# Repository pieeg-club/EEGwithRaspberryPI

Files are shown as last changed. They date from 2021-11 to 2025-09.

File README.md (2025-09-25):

Actual locations for the scripts will be [here](https://github.com/pieeg-club/PiEEG) , now just only Python.

### To Buy - PiEEG is available in the market at our partner shop [Elecrow](https://pieeg.com/pieeg/)

This project is the result of several years of work on the development of BCI. We believe that the easiest way to get started with biosignals is to use a shield.
We will try to reveal the process of reading EEG signals as fully and clearly as possible. 

### GUI
PiEEG it is a low-cost brain-computer interface that allows measuring EEG via RaspberryPI  
[Manual](https://colab.research.google.com/drive/1xW6fwzVdLH83zHoorjeWai6SdZoOanfA#scrollTo=9bxgisvWfs5f)    
[Manual for quick start ](https://github.com/pieeg-club/PiEEG/blob/main/Manual.%20Conenction%20and%20start%20-%20PiEEG1.pdf)    
PiEEG SDK [video maual](https://youtu.be/9jLyN2zRXdU)     
Practical Python Signal Processing [course in Udemy](https://www.udemy.com/course/signal-processing-python-for-eeg/?referralCode=2D537B5EAD7114C43DE2) comfortable for PiEEG 

https://pieeg.com/  
Contact: pieeg@pieeg.com  

aloha

aloha

## Signal test
#### Alpha in EEG signal
aloha

#### Artefacts (chewing and blinking) in EEG signal

artefacts

#### EMG signal
emg

#### EKG signal 
artefacts

#### Pinout between Pi and PiEEG  
 
spi

Connect the shield to Raspberry Pi which is supplied via a 5V battery (power supply) and connect electrodes.
Full galvanic isolation from mains is required.  
This also applies to the monitor. Use only a monitor that is powered by the Raspberry Pi, as in the picture below, left. Electrodes are positioned according to the International 10-20 system, right    
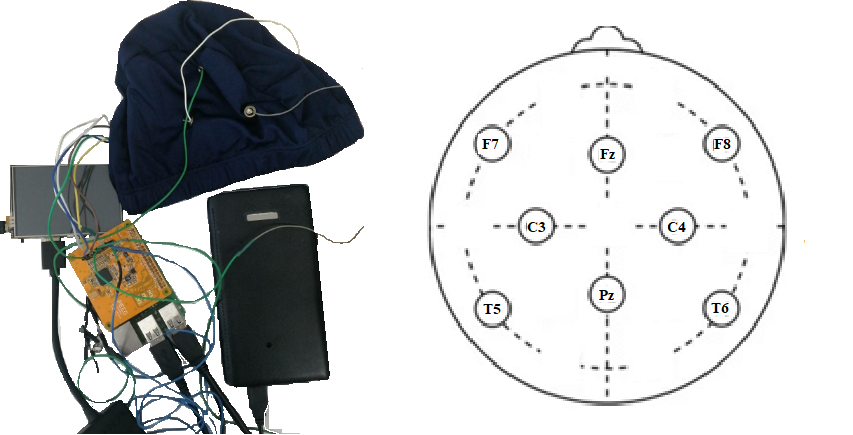
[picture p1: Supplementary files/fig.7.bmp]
general view


#### How to start  
How to start (https://youtu.be/zOxcixEGeE8)  

#### Warnings
>[!WARNING]
> PiEEG  is not medical device. You are fully responsible for your personal decision to purchase this device and, ultimately, for its safe use. PiEEG is not a medical device and has not been certified by any government regulatory agency for use with the human body. Use it at your own risk.  

>[!CAUTION]
> The device must operate only from a battery - 5 V. Complete isolation from the mains power is required.! The device MUST not be connected to any kind of mains power, via USB or otherwise.   
> Power supply - only battery 5V, please read the [liability](https://pieeg.com/liability/)

#### Citation    
I. Rakhmatuiln, et all. (2021). Raspberry Pi Shield - for measure EEG (PIEEG). 2021 5th International Conference on Electrical, Electronics, Communication, Computer Technologies and Optimization Techniques (ICEECCOT), 410-413. DOI: 10.1109/ICEECCOT52851.2021.9707969  [link](https://ieeexplore.ieee.org/document/9707969)

#### Contacts  
http://pieeg.com/  
pieeg@pieeg.com

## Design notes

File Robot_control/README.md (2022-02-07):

# Control the robot by blinking

For example, discrete output channels from GPIO can be connected directly or through a relay to the control panel of radio-controlled toy robots.  
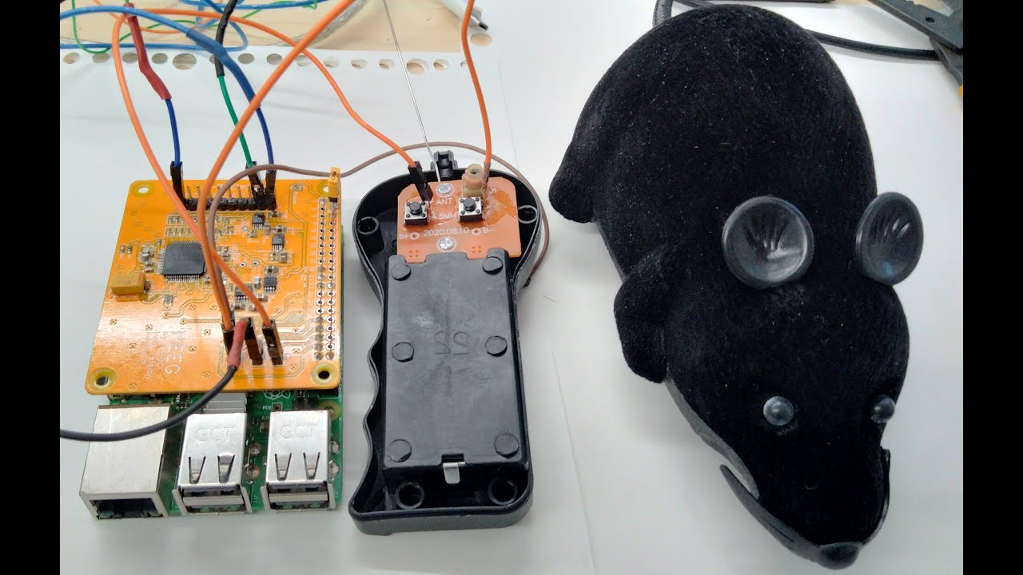
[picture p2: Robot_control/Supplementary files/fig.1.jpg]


Run - robot_control.py   

Connect motor to GPIO in the next points  
GPIO.setup(31, GPIO.OUT)  
GPIO.setup(35, GPIO.OUT)  

set frequency range here - "fourier Transform[0:3]"  
set amplitude here - "blinking_value"   
the best value must be found experimentally    

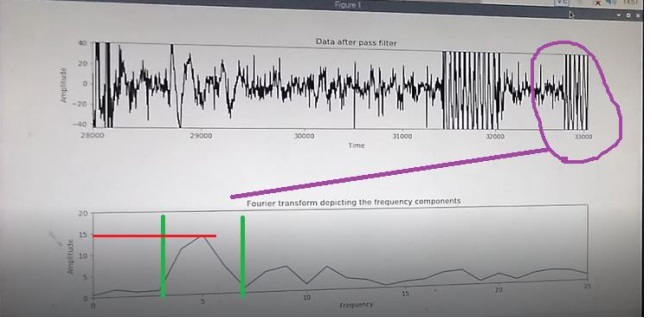
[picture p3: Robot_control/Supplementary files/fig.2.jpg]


(upper graph) - EEG signal through pass filter 1-30 Hz. Lower graph - EEG signal received through the Fast Fourier Transform (the part circled in purple from the graph above). The red line is the setting for turning on the LED, green lines are the frequency range in which we monitor the signal amplitude. (lower graph) – LED circled in blue, output - 31 for GPIO.setmode (GPIO.BOARD)    

We can see in the lower graph for  various frequency ranges, dependence amplitudes from the frequency of  blinking (5 Hz and 3 Hz)
We can set the threshold to the amplitude and connected two diodes. If the amplitude (lower graph) at a frequency of 1-3 Hz becomes more than the threshold, then the upper LED will light up.
If the amplitude (lower graph)  at a frequency of 3-5 Hz becomes more than the threshold, then the lower LED will light up.

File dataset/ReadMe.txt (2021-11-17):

Raw data
1. 1.Shorted_ Raw_Data.txt - Noise measure. The first channel shorted with reference via cable, other channels - internally by register - 0x01.    
2. Artifacts measure. 
3. Alpha rhythm. Soon will be uploaded.

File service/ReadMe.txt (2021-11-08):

VREF = VREFP – VREFN (Note: internal reference buffer must be enabled)
//VCAP1 = AVSS + 1.2 V
VCAP2 = (AVDD + AVSS) / 2
VCAP3 = AVDD + 1.9 V
VCAP4 = (VREFP + VREFN) / 2
VREFP_VREFN  = 4.5 V

VCAP1 = -1.2V

VCAP2 = 0.001V

VCAP3 = 4.2V

VCAP4=-0.125V

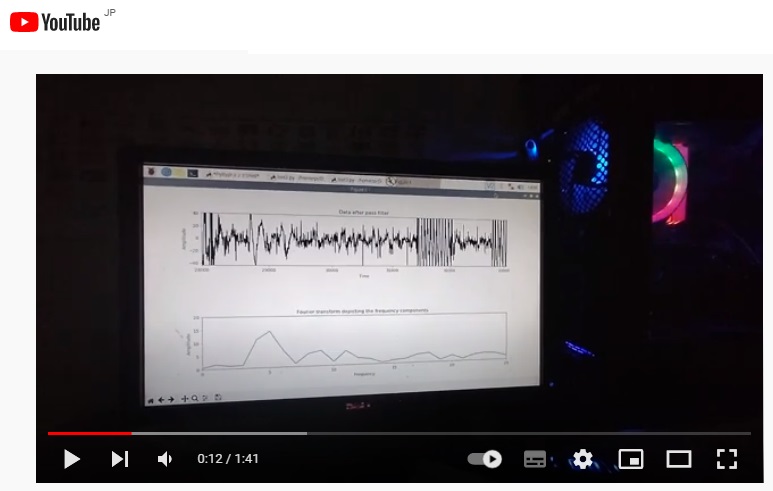
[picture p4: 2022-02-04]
Supplementary files/fig.18.jpg

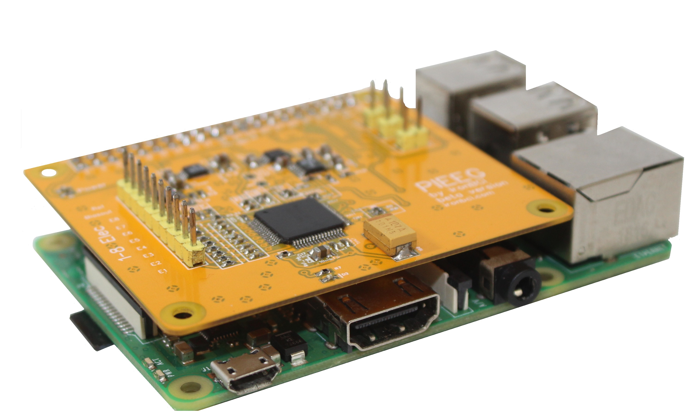
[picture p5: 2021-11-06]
Supplementary files/Fig.3.jpg

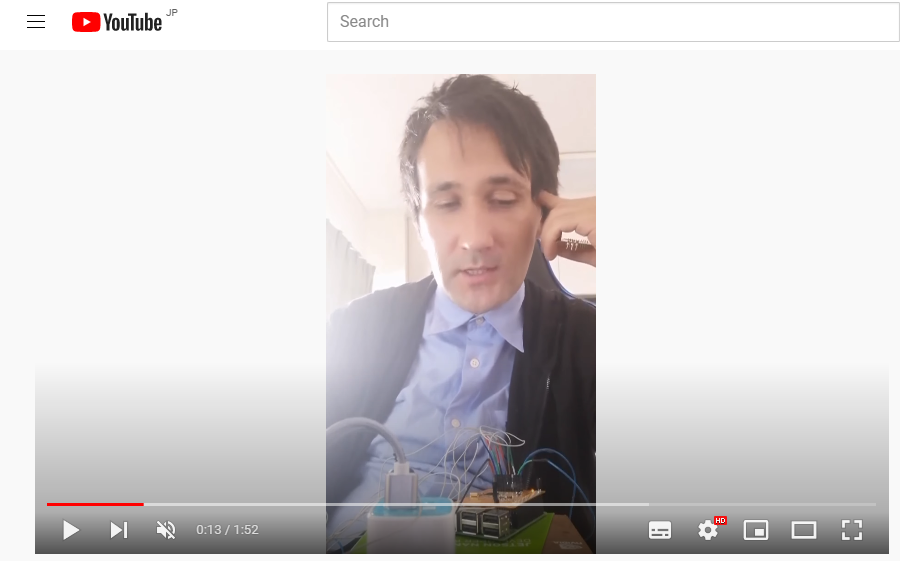
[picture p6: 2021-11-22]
Supplementary files/fig.13.bmp

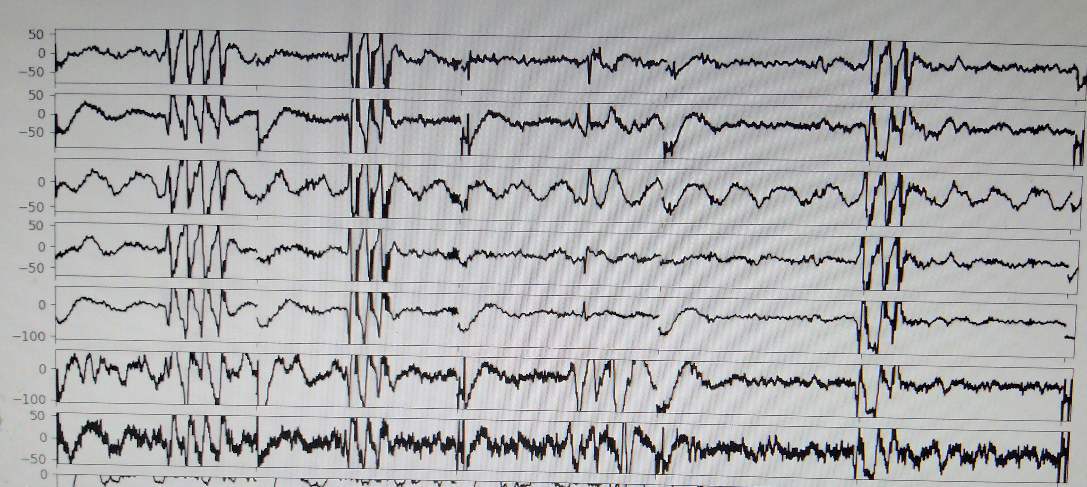
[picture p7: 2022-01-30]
Supplementary files/fig.16.jpg

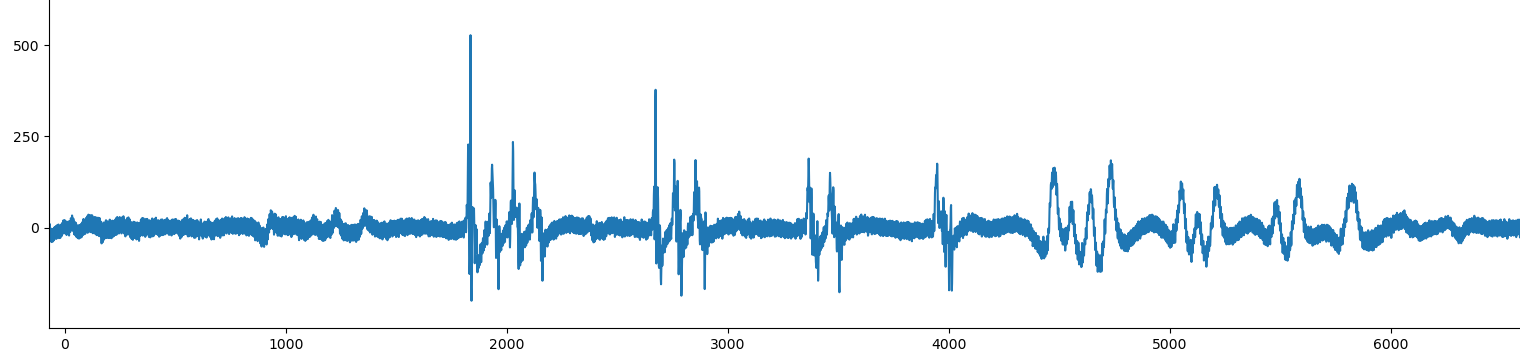
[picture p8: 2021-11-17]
Supplementary files/fig.10.band_bass.bmp

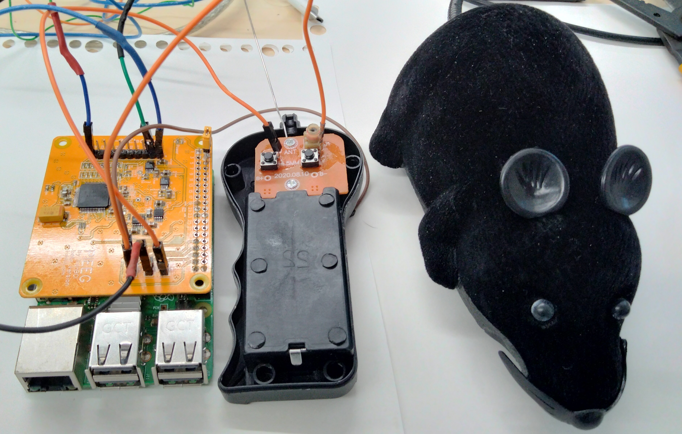
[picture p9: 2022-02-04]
Supplementary files/fig.17.jpg

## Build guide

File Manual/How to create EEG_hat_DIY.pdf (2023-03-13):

DIY - Hat for measuring EEG with dry electrodes for PiEEG

Ildar Rakhmatulin, PhD, PiEEG
ildarr2016@gmail.com

Source https://github.com/Ildaron/EEGwithRaspberryPI

Keywords: PiEEG, EEG, BCI, machine learning, RaspberryPi

Introduction
This document provides step-by-step instructions on how to create a custom Hat for measuring electroencephalography (EEG) signals using dry electrodes, specifically designed for use with PiEEG [1,2,3]. Creating your own Hat for measuring EEG signals with dry electrodes is an affordable and customizable solution for capturing EEG data. This datasheet provides detailed instructions and a list of materials needed to create your Hat, as well as information on how to assemble and use it with your PiEEG. With this DIY approach, you can save costs and have more control over the design of your EEG measurement system. We used available materials without any special skills or tools.

Materials
The electrodes used in this work are Ag-AgCl - Silver chloride electrodes with a hole in the center for installation, Fig.1.

Fig.1. Examples of valid Silver chloride electrodes

To attach the electrode to the hat, a bolt can be used, the diameter of which should be smaller than the hole in the center of the electrode. It is necessary to use bolts with length 3-5 centimeter, washer, nut - M1, Fig.2.

Fig.2. Parts for attaching the electrode to the hat

It is recommended to use Copper cables (stranded, 1-3 mm) as wires, the length is set depending on the needs, Fig.3.

Fig.3. Wires for attaching to the electrode

Strap can be used as hat, for example strap for Camera Mount hat. Electrodes can be located in line international "10-20" electrode placement system, Fig.4.

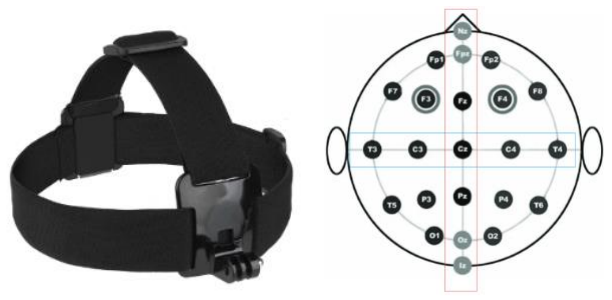
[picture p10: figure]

a | b

Fig.4. a - Camera Mount hat, b – arrange the electrodes according to the international "10-20" electrode placement system

Instructions
Prepare cables. Strip the wires of isolation, a few centimeters, as showed in the Fig. 5.

Fig.5. Cable preparation

To connect the electrode to the cap, it is necessary to take the bolt, nuts, washers, cable - 1 and the EEG cap - 2. First clamp the cable between the nut and the bolt, then thread the bolt through the cap and fix it on the other side with the nut, as shown in Fig.6.

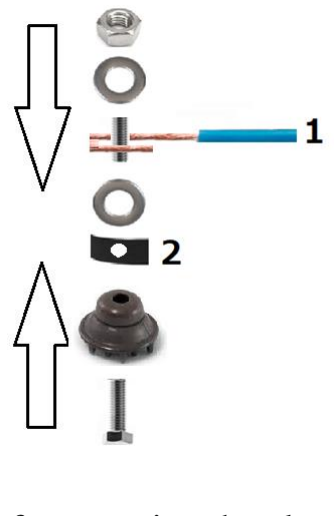
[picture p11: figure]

Fig.6. Scheme of connecting the electrode with a hat

As a result, the prepared electrode should look like shown in Fig.7.

Fig.7. Electrodes prepared for installation in the hat

Next, it is necessary, in accordance with according to the international "10-20" electrode placement system, make holes for electrodes in the hat, insert the electrode and fix it with a bolt from the other side of the hat, Fig. 8.

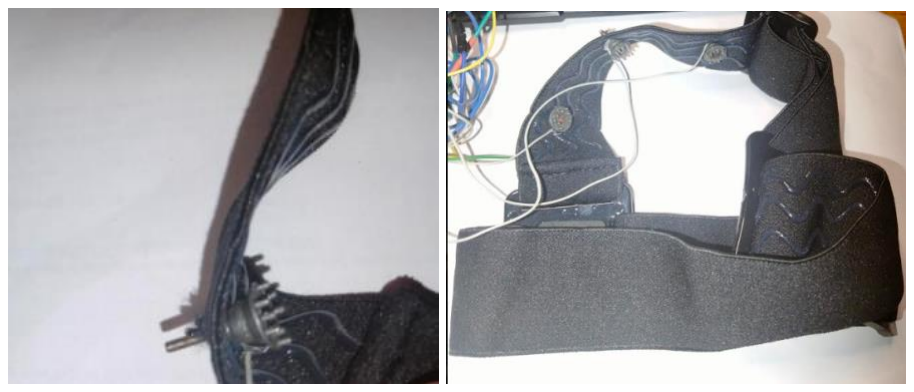
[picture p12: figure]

Fig.8. An example of installing electrodes in a hat

The pressure of the electrode on the head is adjusted independently as far as is comfortable, the clamping force depends largely on the cap material used, and each electrode must be adjusted manually after the cap has been fitted.
The connection of the electrodes to the PEEEG board is shown in Figure 9. Even to measure one EEG channel, 4 electrodes are required, 1 - the EEG electrodes themselves, 2 - the reference electrode, 3 - the ground electrode and 4 - the bias electrode to eliminate common mode interference.

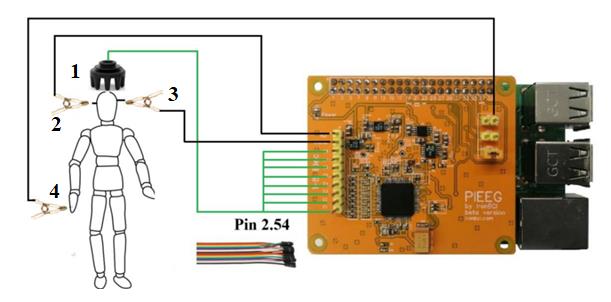
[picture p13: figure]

Fig.9. Scheme of connecting electrodes to the PEEG plan: 1 – EEG electrode, 2 – reference electrode, 3 – ground electrode, 4 – bias electrode

Conclusion
This paper presents one of the simplest ways to make a cheap alternative to a hat for adjusting EEG signals. The main advantage is the low cost. This cap is largely designed to work in conjunction with the PIEEG board and is only intended to be a first step into the world of neuroscience. This is only an example, the ideas proposed in this work can be improved, supplemented, and modified.

Additional Information
- Overview of dry electrodes [4]
- Additional Information Machine learning to identify alcoholism [5]
- Signal processing [6]
- Machine learning for [7]

Conflicts of interest: none Funding: none

Ethical approval: not required

References
1. Rakhmatuiln, I., Zhanikeev, M., and Parfenov, A. (2021). Raspberry PI Shield - for measure EEG (PIEEG)," 2021 5th International Conference on Electrical, Electronics, Communication, Computer Technologies and Optimization Techniques (ICEECCOT), Mysuru, India, 2021, pp. 410-413, doi: 10.1109/ICEECCOT52851.2021.9707969
2. Rakhmatulin, I., Sebastian Volkl, S. (2021). PIEEG: Turn a Raspberry Pi into a Brain-Computer-Interface to measure biosignals. arXiv:2201.02228, https://doi.org/10.48550/arXiv.2201.02228
3. Rakhmatulin, I., Sebastian Volkl, S. (2021). Brain-Computer-Interface controlled robot via RaspberryPi and PiEEG. arXiv:2202.01936. https://doi.org/10.48550/arXiv.2202.01936
4. Rakhmatulin, I.; Gan, Y. Review Dry and Non-Contact EEG Electrodes for 2010-2021 Years. Preprints 2021, 2021030555. https://doi.org/10.20944/preprints202103.0555.v1
5. Rakhmatulin, I. (2021). Deep learning and machine learning for EEG signal processing on the example of recognizing the disease of alcoholism. Medrxiv. doi: https://doi.org/10.1101/2021.06.02.21258251
6. Rakhmatulin, Ildar, Review of EEG Feature Selection by Neural Networks (August 17, 2020). International Journal of Science and Business, Volume 4, issue 9, 101-112, 2020 DOI: 10.5281/zenodo.3987894, ISSN 2520-4750 (Online) & ISSN 2521-3040 (Print), Available at SSRN: https://ssrn.com/abstract=3675950 or http://dx.doi.org/10.2139/ssrn.3675950
7. Rakhmatulin, I. (2021). Progress in neural networks for EEG signal recognition in 2021. arXiv:2103.15755. https://doi.org/10.48550/arXiv.2103.15755

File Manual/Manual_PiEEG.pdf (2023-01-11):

RaspberryPi to measure EEG, ECG, EMG and EOG with Shield PiEEG

In this paper presented hardware and software for shield PiEEG for reading signals through the families of single-board computers - RaspberryPi, OrangePi, BananaPi, etc. For the most part, the paper provides technical information on how to implement this device. This device is designed to be familiar with neuroscience and is one of the easiest ways to get started with EEG measurements.

Ildar Rakhmatulin, PhD, PiEEG, ildarr2016@gmail.com
Source https://github.com/Ildaron/EEGwithRaspberryPI
Presentation https://youtu.be/uK8QF2liO5U

Keywords: RaspberryPi and EEG, ECG, EMG and EOG; brain-computer interface; shield for RaspberryPi

### 1. Introduction

The brain-computer interface is a device for reading brain signals in order to identify any correlations that can be used for practical purposes. In 2021 we developed the brain-computer interface - ironbci [1,2,3] but the chip shortage significantly increased the cost of the device, after which we switched to PiEEG shield, which made it possible to reduce the cost of the device and simplify the installation process. The PiEEG device was presented in general terms at the conference [4] and in the publication [10]. In this paper we will focus more on the technical details of the implementation of this device.

### 2. Safety recommendation

The developed device was tested only for Raspberry Pi. During the test, it is forbidden connect the device to the electrical source, this need for safety and to avoid network interference. Cannot be used this device when powered via an electrical network and used it only when working with 5V batteries (capacity– not mote 2000 mAh). General view of the complete assembly of the device in Fig.1.

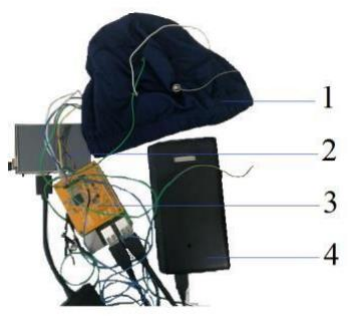
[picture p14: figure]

Fig.1 General View of assembled device: 1 – hat EEG, 2 – monitor, 3 – RaspberryPI and shield EEG, 4 – power bank

All parts should be connected only with battery – monitor, keyboard, mouse, RaspberryPI and PiEEG device. The device is connected only directly through GPIO40 to the Raspberry Pi. There must not be any connections for any elements with the electrical network.
Also observe the following protective measures:
- If the device fails (heating of components, smoke etc. ), switch off immediately;
- When you have finished using any electrical appliance, be sure to turn it off and unplug it;
- Never try to fix a malfunction in an electrical appliance yourself;
- Do not touch the components on the board when the device is turned on.

### 3. Connecting the device

The device is designed to allow single-board computers to read the EEG signal via the SPI protocol from ADS1299. The next single computers can be connected (not tested yet) - OrangePi, BananaPi, and the device can be connected via wires to the input of the microcontroller if necessary, Fig.2.

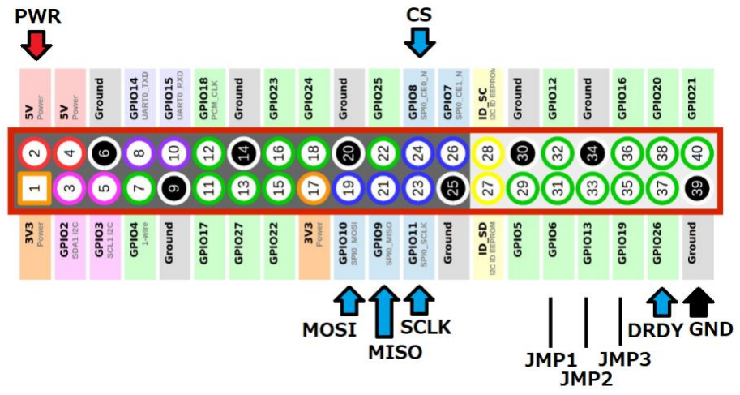
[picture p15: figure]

Fig.2. Device connection scheme, GPIO40

### 4. Software

Data transfer between Raspberry Pi and ADS1299 using the SPI protocol is written in C at a rate of 250 samples per second for each channel. Data processing realized in Python 3. Software files details from https://github.com/Ildaron/EEGwithRaspberryPI/tree/master/GUI :
libperiphery.a (https://github.com/Ildaron/EEGwithRaspberryPI/blob/master/GUI/libperiphery.a) – static library compiled from https://github.com/vsergeev/c-periphery ,
real_time.py (https://github.com/Ildaron/EEGwithRaspberryPI/blob/master/GUI/real_time.py) – script for editing processing signal and data visualization,
real_time_massive.c (https://github.com/Ildaron/EEGwithRaspberryPI/blob/master/GUI/real_time_massive.c) – header call,
real_time_massive.h (https://github.com/Ildaron/EEGwithRaspberryPI/blob/master/GUI/real_time_massive.h) – register setting for data transfer protocol,
super_real_time_massive.so (https://github.com/Ildaron/EEGwithRaspberryPI/blob/master/GUI/super_real_time_massive.so) – compiled dynamic library.

To start the reading EEG signals is possible to write software or download from the git https://github.com/Ildaron/EEGwithRaspberryPI , then go to the folder - GUI and run the file -real_time.py. An example of reading is shown in the figure in Fig.3.

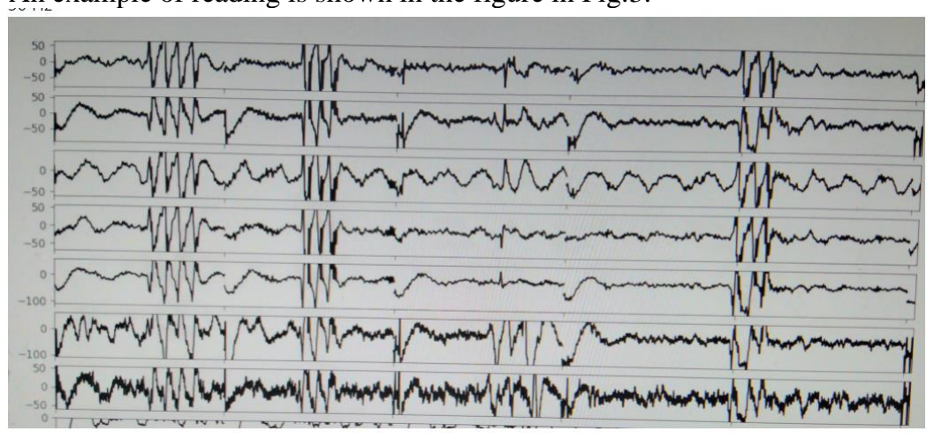
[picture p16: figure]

Fig.3. EEG signals after band pass filter 1-30 Hz

Through the python script, is possible to configure the parameters for band pass filters. Signal processing is implemented using the standard scipy library. Through the C file, once per second we receive a data packet of 2000 data, 250 samples per second for each channel.
Currently we used the next setting for registers for ADS1299:
write_reg (0x14,0x80);//led write_reg (0x05,0x00);//ch1 write_reg (0x06,0x01);//ch2 write_reg (0x07,0x01);//ch3 write_reg (0x08,0x01);//ch4 write_reg (0x0D,0xFF);//bias N write_reg (0x0E,0x00);//bias P write_reg (0x09,0x01);//ch5 write_reg (0x0A,0x01);//ch6 write_reg (0x0B,0x01);//ch7 write_reg (0x0C,0x01);//ch8 write_reg (0x15,0x20);// mics write_reg (0x01,0x96);// reg1 write_reg (0x02,0xD4);// reg2 write_reg (0x03,0xE0);// reg3 send_command (0x10);//sdatc send_command (0x08);//start

To change the ADS1299 registers, needs to work with the header file - real_time_massive.h, after any changes, need to recompile the static library, following the next steps for GPIO library for Linux from https://github.com/vsergeev/c-periphery:
$ mkdir build
$ cd build
$ cmake ..
$ make
That allows receiving the Static Library - libperiphery.a and finally to create a dynamic library for .so -
gcc | -shared | -home/pi/Desktop/new_spi/c-periphery-master/src | real_time_massive.c
/home/pi/Desktop/new_spi/c-periphery-master/build/libperiphery.a -o super_real_time_massive.so This library can be imported in python script with signal processing (example - real_time.py) via standard library – ctypes.
In case of errors incompatibility in a python IDE, it is necessary to check the versions of installed libraries https://github.com/Ildaron/EEGwithRaspberryPI/blob/master/pip.txt
The PIEEG device has a diode connected to the ADS1299, which lights up when the PiEEG device is initialized. If the life bit is not burning, it is necessary to check the power (Fig.4) in the next points:
| TP1: – 2.5V TP2: 3.3V TP3: 2.5V

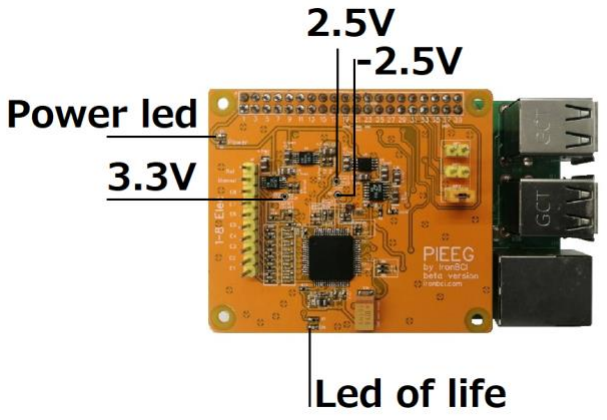
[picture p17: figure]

Fig.4. Test points in the PiEEG board

If there is noise in the measured EEG signals that goes beyond the limits declared in the device it is necessary to check the voltage in the next points:
VCAP1 = -1.2V
VCAP2 = 0.001V
VCAP3 = 4.2V
VCAP4=-0.125V

### 5. Conclusion and perspectives

This device is positioned as an easy way to start measuring EEG signals. We introduced hardware and software for reading and processing data in real-time in open source format. We demonstrated how to control a robot using a device [5], in the future we will work on the P300 and on other paradigms, then we plan to gather a team of like-minded people and collect the necessary amount of data to control robots through the motor imagery method. Fig.5 shows a block diagram for the possibility areas of use of the device.

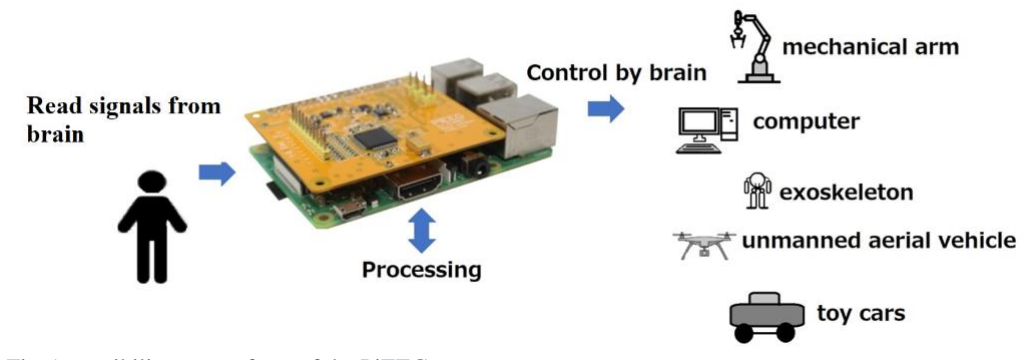
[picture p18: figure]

Fig.5. possibility areas of use of the PiEEG

Additional Information
Machine learning to identify alcoholism [9], Overview of dry electrodes [6],
Signal processing [7,8] .

References
1. Rakhmatulin, I., Parfenov, A., Traylor, Z. et al. (2021). Low-cost brain computer interface for everyday use. ExpBrain Res 239, 3573–3583. https://doi.org/10.1007/s00221-021-06231-49
2. Rakhmatulin, I. (2021). ironbci - Open-source Brain-computer interface with the embedded board to monitor the physiological subject's condition and environmental parameters arXiv:2111.03656
3. Rakhmatulin, I . (2021). The electronic board to replace the reference voltage on the earlobe for EEG measurement. March 2021Measurement 173 DOI: 10.1016/j.measurement.2020.108673
4. Rakhmatulin, I. et al. (2021). Raspberry PI Shield - for measure EEG (PIEEG). Conference: 2021 5th International Conference on Electrical, Electronics, Communication, Computer Technologies and
Optimization | Techniques | (ICEECCOT). | DOI: | 10.1109/ICEECCOT52851.2021.9707969
5. I Rakhmatulin, S Volkl. (2022). Brain-Computer-Interface controlled robot via RaspberryPi and PiEEG, arXiv preprint arXiv:2202.01936
6. Rakhmatulin, I., Gan, Y. Review Dry and Non-Contact EEG Electrodes for 2010-2021 Years. Preprints 2021, 2021030555. doi:10.20944/preprints202103.0555.v1
7. Rakhmatulin, I. (2020). Review of EEG Feature Selection by Neural Networks. Int. J. Sci. Bus. 2020, 4, 101–112. http://dx.doi.org/10.2139/ssrn.3675950
8. Ildar, R. (2021). Progress in neural networks for EEG signal recognition in 2021. arXiv preprint arXiv:2103.15755
9. Rakhmatulin, I. (2020). Deep learning and machine learning for EEG signal processing on the example of recognizing the disease of alcoholism. https://doi.org/10.1101/2021.06.02.21258251
10. I Rakhmatulin, S Volkl. (2022). PIEEG: Turn a Raspberry Pi into a Brain-Computer-Interface to measure biosignals. arXiv:2201.02228

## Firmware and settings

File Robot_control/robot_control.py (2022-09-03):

import ctypes
import time
import numpy as np
from numpy.ctypeslib import ndpointer
import sys
import pandas as pd
from scipy import signal
import matplotlib.pyplot as plt
import threading
from RPi import GPIO
import scipy.fftpack

GPIO.setmode(GPIO.BOARD)
GPIO.cleanup()
GPIO.setwarnings(False)
GPIO.setup(31, GPIO.OUT)
GPIO.setup(35, GPIO.OUT)

np.set_printoptions(threshold=sys.maxsize)
libc = ctypes.CDLL("./super_real_time_massive_sec.so")
libc.prepare()

def receive_data():
    libc.real.restype = ndpointer(dtype = ctypes.c_int, shape=(sample_len,8))    
    datas=libc.real()
    data=datas.copy()
    return data

def butter_bandpass(lowcut, highcut, fs, order=5):
    nyq = 0.5 * fs
    low = lowcut / nyq
    high = highcut / nyq
    b, a = signal.butter(order, [low, high], btype='band')
    return b, a
 	 
def butter_bandpass_filter(data, lowcut, highcut, fs, order=5):
    b, a = butter_bandpass(lowcut, highcut, fs, order=order)
    data = signal.lfilter(b, a, data)
    return data

def graph (ch,a):
 data = (data_array[:,[ch]])
 data = list(data.flatten())
 
 sine ['data'+str(a)] = data
 if a==0:
  z = sine ['data1']           
  z = np.append(z, (sine ['data2']))
  z = np.append(z, (sine ['data3']))
  z = np.append(z, (sine ['data4']))
  z = np.append(z, (sine ['data5']))
  z = np.append(z, (sine ['data6']))
  z = np.append(z, (sine ['data7']))
  z = np.append(z, (sine ['data0']))
 if a==1:
  z = sine ['data2']          
  z = np.append(z, (sine ['data3']))
  z = np.append(z, (sine ['data4']))
  z = np.append(z, (sine ['data5']))
  z = np.append(z, (sine ['data6']))
  z = np.append(z, (sine ['data7']))
  z = np.append(z, (sine ['data0']))
  z = np.append(z, (sine ['data1']))                      
 if a==2:
  z = sine ['data3']         
  z = np.append(z, (sine ['data4']))
  z = np.append(z, (sine ['data5']))
  z = np.append(z, (sine ['data6']))
  z = np.append(z, (sine ['data7']))
  z = np.append(z, (sine ['data0']))
  z = np.append(z, (sine ['data1']))
  z = np.append(z, (sine ['data2']))                        
 if a==3:
  z = sine ['data4']   
  z = np.append(z, (sine ['data5']))
  z = np.append(z, (sine ['data6']))
  z = np.append(z, (sine ['data7']))
  z = np.append(z, (sine ['data0']))
  z = np.append(z, (sine ['data1']))
  z = np.append(z, (sine ['data2']))
  z = np.append(z, (sine ['data3']))            
 if a==4:      
  z = sine ['data5']   
  z = np.append(z, (sine ['data6']))
  z = np.append(z, (sine ['data7']))
  z = np.append(z, (sine ['data0']))
  z = np.append(z, (sine ['data1']))
  z = np.append(z, (sine ['data2']))
  z = np.append(z, (sine ['data3']))
  z = np.append(z, (sine ['data4']))            
 if a==5:       
  z = sine ['data6']   
  z = np.append(z, (sine ['data7']))
  z = np.append(z, (sine ['data0']))
  z = np.append(z, (sine ['data1']))
  z = np.append(z, (sine ['data2']))
  z = np.append(z, (sine ['data3']))
  z = np.append(z, (sine ['data4']))
  z = np.append(z, (sine ['data5']))            
 if a==6:      
  z = sine ['data7']        
  z = np.append(z, (sine ['data0']))
  z = np.append(z, (sine ['data1']))
  z = np.append(z, (sine ['data2']))
  z = np.append(z, (sine ['data3']))
  z = np.append(z, (sine ['data4']))
  z = np.append(z, (sine ['data5']))
  z = np.append(z, (sine ['data6']))          
 if a==7:        
  z = sine ['data0']     
  z = np.append(z, (sine ['data1']))
  z = np.append(z, (sine ['data2']))
  z = np.append(z, (sine ['data3']))
  z = np.append(z, (sine ['data4']))
  z = np.append(z, (sine ['data5']))
  z = np.append(z, (sine ['data6']))
  z = np.append(z, (sine ['data7']))
 
 #data = pd.DataFrame({'data': z} )
  
 data = z
 #print ('sine', data[250:])
 data_band = butter_bandpass_filter(data, cutoff, cutoffs,fps)

 data_after_filter=data_band[1750:]
 return data_after_filter

sines=list(range(0,250,1))
sine = pd.DataFrame({'data': sines} )
zet=sine.values
sine ['data0'] = sine
sine ['data1'] = zet
sine ['data2'] = zet
sine ['data3'] = zet
sine ['data4'] = zet
sine ['data5'] = zet
sine ['data6'] = zet
sine ['data7'] = zet

sample_len = 250
fps = 250
cutoff=1
cutoffs = 30
figure, axis = plt.subplots(2, 1)
plt.subplots_adjust(hspace=1)

axis_x=0
y_minus_graph=100
y_plus_graph=100
x_minux_graph=5000
x_plus_graph=50

#plt.title('Channel 1')
#plt.xlabel('sample')
#plt.ylabel('EEG Voltage')

def read_data_thread():
    global data_was_received
    data_was_received = False
    while 1:       
        global data_array
        data_array=receive_data()
        data_was_received = not data_was_received

def start_thread_read_data():
    thread = threading.Thread(target=read_data_thread)
    thread.start()

start_thread_read_data()

data_for_shift_filter=([[1],[2],[3],[4],[5],[6],[7],[8]])
data_was_received_test=True
fill_array=0

axis[0].set_xlabel('Time')
axis[0].set_ylabel('Amplitude')
axis[0].set_title('Data after pass filter')
samplingFrequency   =  250 
blinking_value =10


a=0
while 1: 
    if (data_was_received_test == data_was_received):
        data_was_received_test = not data_was_received_test

        axis[1].cla()
        axis[1].set_title('Fourier transform depicting the frequency components')
        axis[1].set_xlabel('Frequency')
        axis[1].set_ylabel('Amplitude')
        #for channel in (range(0,8,1)):
        channel=0

        data=graph(channel,a)
        a=a+1
        if (a == 8):
         a=0

        fourierTransform = np.fft.fft(data)/len(data)           
        fourierTransform = fourierTransform[range(int(len(data)/2))] 
        tpCount     = len(data)
        values      = np.arange(int(tpCount/2))
        timePeriod  = tpCount/samplingFrequency
        frequencies = values/timePeriod

        axis[1].plot(frequencies, abs(fourierTransform))        
        axis[1].axis([0, 25, 0, 20])        
        axis[0].plot(range(axis_x,axis_x+sample_len,1),data,color = '#0a0b0c')
        axis[0].axis([axis_x-x_minux_graph, axis_x+x_plus_graph, data[50]-y_minus_graph, data[150]+y_plus_graph])

        axis_x=axis_x+sample_len      
        plt.pause(0.000001)
        
        GPIO.output(35,False )
        GPIO.output(31, False)
        print ('0:3', max(abs(fourierTransform[0:3])))
        print ('3:5', max(abs(fourierTransform[3:5])))
        if (blinking_value<max(abs(fourierTransform[0:3]))):
            GPIO.output(35, True)
            GPIO.output(31, False)

        if (blinking_value<max(abs(fourierTransform[3:5]))):
            GPIO.output(35, False)
            GPIO.output(31, True)

        plt.draw()

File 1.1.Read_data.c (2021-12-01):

// create file data.txt in the folder with the script 

#include <stdio.h>
#include <stdlib.h>
#include <stdint.h>
#include "spi.h"
#include "gpio.h"
#include <unistd.h>

int main(void) 
{      
    gpio_t *gpio_in;
    gpio_in = gpio_new();
    gpio_open (gpio_in, "/dev/gpiochip0", 26, GPIO_DIR_IN);

    spi_t *spi;
    spi = spi_new();
    int spi_open = spi_open_advanced(spi, "/dev/spidev0.0", 0x01, 1000000, MSB_FIRST, 8, 1);
        if (spi_open == 0)
        {
             printf("spi_open_error"); 
        }
        
        
    void write_reg(uint8_t reg_address, uint8_t val_hex)
           {
           uint8_t zero3[3] = {0x00, 0x00,0x00}; 
           uint8_t reg_address_shift = 0x40 | reg_address;
           uint8_t write [3] = {reg_address_shift, 0x00,val_hex};
           int spi_reg = spi_transfer (spi, write, zero3, 3);
             if (spi_reg == 1)
             {
             printf("spi_reg_error"); 
             }
             
           }
    void send_command(uint8_t command)
           {
           uint8_t zero1[1] = {0x00};
           uint8_t write_command [1] = {command};
           int spi_com = spi_transfer (spi, write_command, zero1, 1);
            if (spi_com == 1)
             {
             printf("spi_com_error"); 
             }
           }        
          write_reg (0x14,0x80);//led
          write_reg (0x05,0x00);//ch1
          write_reg (0x06,0x01);//ch2
          write_reg (0x07,0x01);//ch3
          write_reg (0x08,0x01);//ch4
          write_reg (0x09,0x01);//ch5
          write_reg (0x0A,0x01);//ch6
          write_reg (0x0B,0x01);//ch7
          write_reg (0x0C,0x01);//ch8
          write_reg (0x15,0x20);// mics
          write_reg (0x01,0x96);// reg1
          write_reg (0x02,0xD4);// reg2
          write_reg (0x03,0xE0);// reg3
          send_command (0x10);//sdatc
          send_command (0x08);//start

uint8_t buf[27] = {0}; 
float package [8]={0};   
uint32_t data_test = 0x7FFFFF;
uint32_t data_check = 0xFFFFFF;
uint8_t zero27[27] = {0x00}; 
// int count = 0;

int gpio_edge = gpio_set_edge (gpio_in, GPIO_EDGE_FALLING);  
        if (gpio_edge == 0)
        {
             printf(" GPIO_EDGE_FALLING_error"); 
        }
int timeout_ms = 1000;
FILE *file = fopen("data.txt", "w");
fprintf(file,"ch1 ch2 ch3 ch4 ch5 ch6 ch7 ch8\n");
while (1)  
 {      usleep(100); 
        int gpio_res = gpio_poll (gpio_in, timeout_ms);  
      
        if (gpio_res == 1)
        {   //usleep(100); 
            gpio_edge_t edge = GPIO_EDGE_NONE;
            gpio_res = gpio_read_event (gpio_in, &edge, NULL);
            
            int spi_send = spi_transfer (spi, zero27, buf, 27);
             if (spi_send == 1)
             {
             printf("spi_send_error"); 
             }
                 // count=count+1;
                 // fprintf(file, "%d", count);
      
                 for (int i = 1; i<9; i++)  
                {
                                
                int offset = 3*i;
                uint32_t voltage = (buf[offset] << 8) | buf[offset+1];
                voltage = (voltage << 8) | buf[offset+2];
                uint32_t voltage_test = voltage | data_test;

                    if (voltage_test == data_check)
                    {
                    voltage = 16777214 - voltage;                   
                    }

                  package[i-1]=0.27*voltage;   // (4.5*1000000/16777214)=0.27 
                 // fprintf(file,"data");
                //   fprintf(file," ");
                  fprintf(file, "%.1f", package[i-1]);
                  fprintf(file," ");
                } 
                  fprintf(file,"  \n");
             
            printf("%.1f\n", package[0]); // 0 - first chanel
      }
      else
      { 
          printf("ADS1299 dont send data");
      }  
      
 }
  spi_close(spi);
  spi_free(spi);
  gpio_close(gpio_in);
  gpio_free(gpio_in);
  fclose(file);
return 0;
}
